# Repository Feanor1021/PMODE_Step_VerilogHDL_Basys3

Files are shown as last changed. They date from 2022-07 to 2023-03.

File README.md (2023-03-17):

# PMODE Step VerilogHDL Basys3

Basys3 Board

This project contains the Verilog HDL code for implementing a PMODE step on the Basys3 FPGA development board.

## Overview

The PMODE step is a useful circuit for controlling the direction of rotation of a stepper motor. The PMODE step circuit consists of four switches (SW0-SW3) and four output pins (LED0-LED3). When the switches are pressed in a particular sequence, the corresponding LED pins will light up in a particular sequence. This sequence of LED pin activations determines the direction and speed of the stepper motor.

PMODE Step Circuit

## Design

The PMODE step circuit is implemented using Verilog HDL. The design consists of a state machine that controls the behavior of the circuit based on the input from the four switches. The state machine has four states, each corresponding to a particular sequence of LED pin activations. The state machine transitions between these states based on the input from the switches.

The Verilog HDL code is written to be compatible with the Basys3 FPGA development board. The input signals are read from the switches and the output signals are written to the LED pins on the board.

## Usage

To use this Verilog HDL code on the Basys3 FPGA development board, follow these steps:

1. Clone or download this repository.
2. Open the project in a Verilog HDL synthesis tool such as Xilinx Vivado or Intel Quartus Prime.
3. Synthesize the design and generate the bitstream.
4. Program the bitstream onto the Basys3 FPGA development board.

Once the bitstream has been programmed onto the board, you can test the circuit by pressing the switches in the appropriate sequence and observing the LED pins.

## Credits

This project was developed by [Feanor1021](https://github.com/Feanor1021). The author would like to acknowledge the contributions of the Xilinx Vivado and Intel Quartus Prime tools to this project.

## License

This project is licensed under the MIT License. See the [LICENSE](LICENSE) file for details.

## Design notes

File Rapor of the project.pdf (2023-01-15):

Stepper Motor PMOD Reference Document

pg. 1

### KOCAELİ UNIVERSITY ENGINEERING FACULTY

# STEPPER MOTOR

# PMOD REFERENCE

# DOCUMENT

FURKAN YARDIMCI
2021-2022

### DEPARTMENT: Electronic and Communacition Engineering TEACHER: Associate Profesor ANIL ÇELEBİ

### KOCAELİ, 2021

TABLE OF CONTENTS

TABLE OF CONTENTS | 2
LIST OF FIGURES | 2
LIST OF TABLES | 2
PURPOSE OF THE PROJECT | 3
INTRO/OVERWİEV | 3
FEATURES | 3
CONNECTİONS/INTERFACING | 3
STEPPER MOTOR CONTROL | 4
VERILOG HDL | 5
•CODE | 5-9
- PMOD_STEP_DRIVER.V | 5-7
- CLOCK_DIV.V | 8
- PMOD_STEP_INTERFACE.V | 9
SCHEMATIC | 10
BORD LAYOUT | 10-12
MATERIAL LIST | 13
REFERENCES | 14

LIST OF FIGURES

STATE DIAGRAM OF THE CODE | 5
SCHEMATIC OF THE CIRCUIT | 10
TOP | 10
BOTTOM | 11
TOP/BOTTOM | 11
FOTAGE OF THE CIRCUIT(TOP) | 12
FOTAGE OF THE CIRCUIT(BOTTOM) | 12
MATERIAL LIST | 13

LIST OF TABLES

TABLE OF CONTENTS | 4
PURPOSE OF THE PROJECT | 4

PURPOSE:

The purpose of this document is to provide a document containing the necessary features about the design and use of stepper motor pmod, prepared by Kocaeli University Students FURKAN YARDIMCI and ASLINUR SERİN.

İNTRO/OVERWİEV:

The pmod stepper motor module provides the required number of headers to drive the 4-pin bipolar and 6-pin unipolar stepper motors with the Basys-3 board. Stepper motors are structures that contain magnets and coils that polarize this magnet to provide movement. When electric current passes through the coils in stepper motors, the motor creates torque due to the magnetic field created by this current. Each movement of this motor is called a step. The inputs of the Basys-3 card cannot provide this current required for the step motor to work. With the current/power amplifier circuit consisting of LM293D and mosfets on the pmod stepper module, it increases the low current it receives from the Basys-3 card to the levels that required for driving the stepper motor. In this way, the stepper motor is driven.

FEATURES:

- Stepper motor driver for 4 and 6-pin motors
- Can drive both motors simultaneously
- Multiple LEDs to indicate signal propagation
- Jumper for optional external power
- 2×6-pin pmod connector with GPIO interface

CONNECTİONS/INTERFACİNG:

The Pmod STEP communicates with the host board via the GPIO (General-purpose input/output) protocol. Microcontrollers usually include GPIOs. Depending on the application, a microcontroller's GPIOs may comprise its primary interface to external circuitry or they may be just one type of I/O used among several, such as analog signal I/O, counter/timer, and serial communication.

This Pmod offers headers for both 4-pin and 6-pin stepper motors. 4-pin stepper motors only work in the bipolar configuration, requiring that the two inputs on each electromagnetic coil are brought to the correct logic level voltages to induce current flow in the correct direction. The 6-pin stepper motor header on this Pmod can be oriented for either bipolar or unipolar configuration. The two extra pins on this header provide two positive power pins as a source of current for when an input on one end of a coil is driven to a logic low voltage level.

SM PMOD Reference Designator | Function
P2 | This pin 2x6, right-angle header provides VCC, GND and (8) digital 1/0 signals from the Basy3's microcontroller to the SM PMOD through any of the Pmod connector ports on the Basys-3.

P3 | 4-wire stepper motor interface connector.
P4 | 6-wire stepper motor interface connector.
P9 | This header provides access to pins 1-4 of the SM PMOD header J1 (labeled SIG1-SIG4 on the SM PMOD schematic).
P10 | This header provides access to pins 5-8 of the SM PMOD header J1 (labeled SIG5-SIG8 on the SM PMOD schematic).
P7 | GND
P8 | GND
P6 | External power screw terminal block. Provide power to the SM PMOD from an external source rather than from the Basys-3 board. NOTE: Pins 1 and 3 of P5 must be shorted (pins 2 and 3 of P5 open) to power the SM PMOD from an external source.
J1 | External power measurement point. Use P7 or P8 (GND) on SM PMOD as the return to measure the voltage of the external power applied to the board.
P5 | Power selection jumper. Jumper (short) pins 1 and 2 of P5 to supply power from the external power screw terminal block P6 or jumper (short) pins 2 and 3 of P5 to supply power from the Basys-3 board.
P1 | Digital I/O signal state indication LED power jumper. Install the jumper (short pins 1 and 2) on P1 to provide power to bias the digital 1/0 signal state indication LEDs. Remove the jumper to reduce power consumption of board for battery powered applications.

TABLE 1.

STEPPER MOTOR CONTROL:

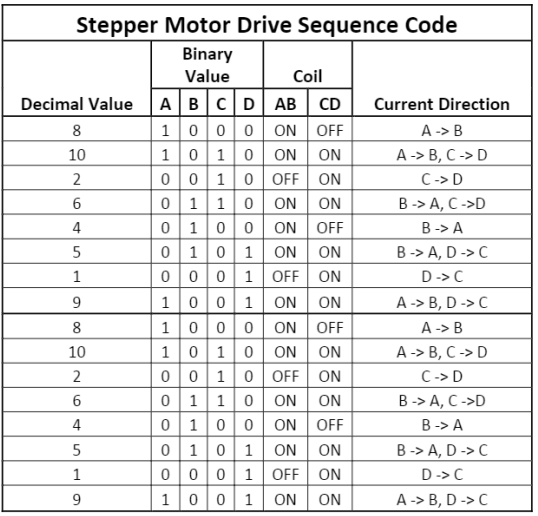
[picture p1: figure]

TABLE 2

VERİLOG HDL:

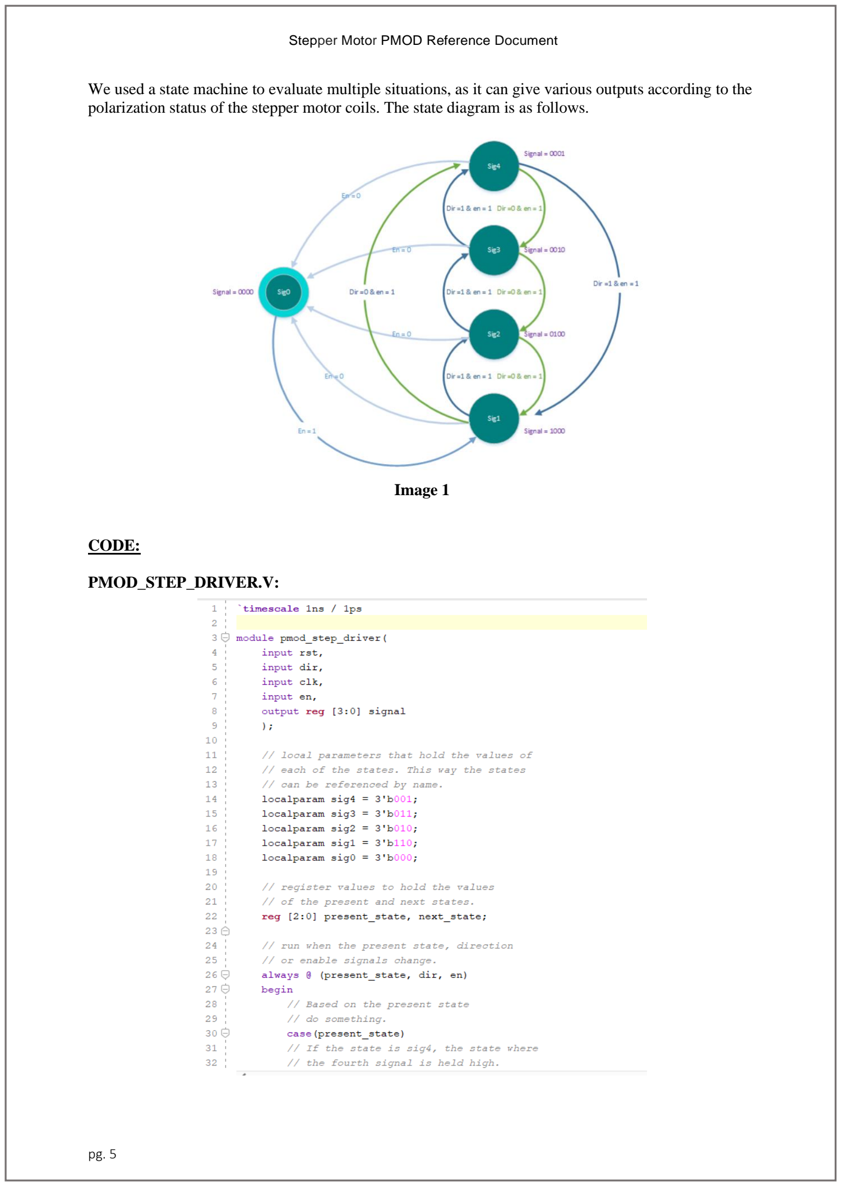
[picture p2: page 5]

We used a state machine to evaluate multiple situations, as it can give various outputs according to the polarization status of the stepper motor coils. The state diagram is as follows.

Image 1

CODE:

PMOD_STEP_DRIVER.V:

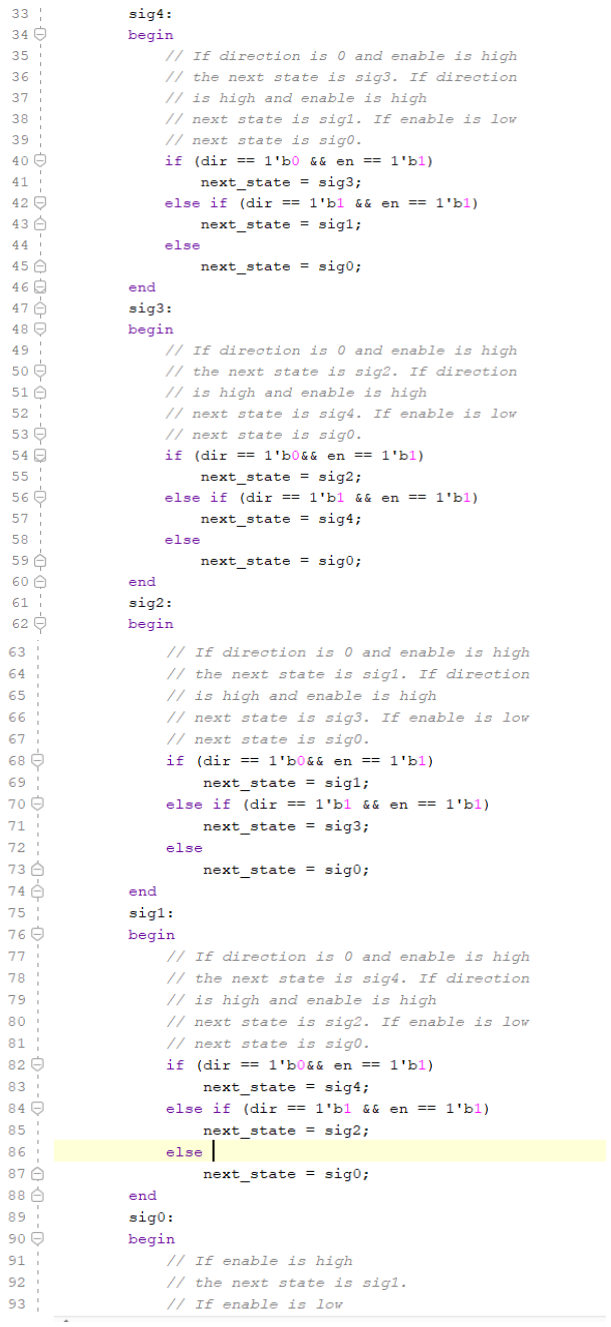
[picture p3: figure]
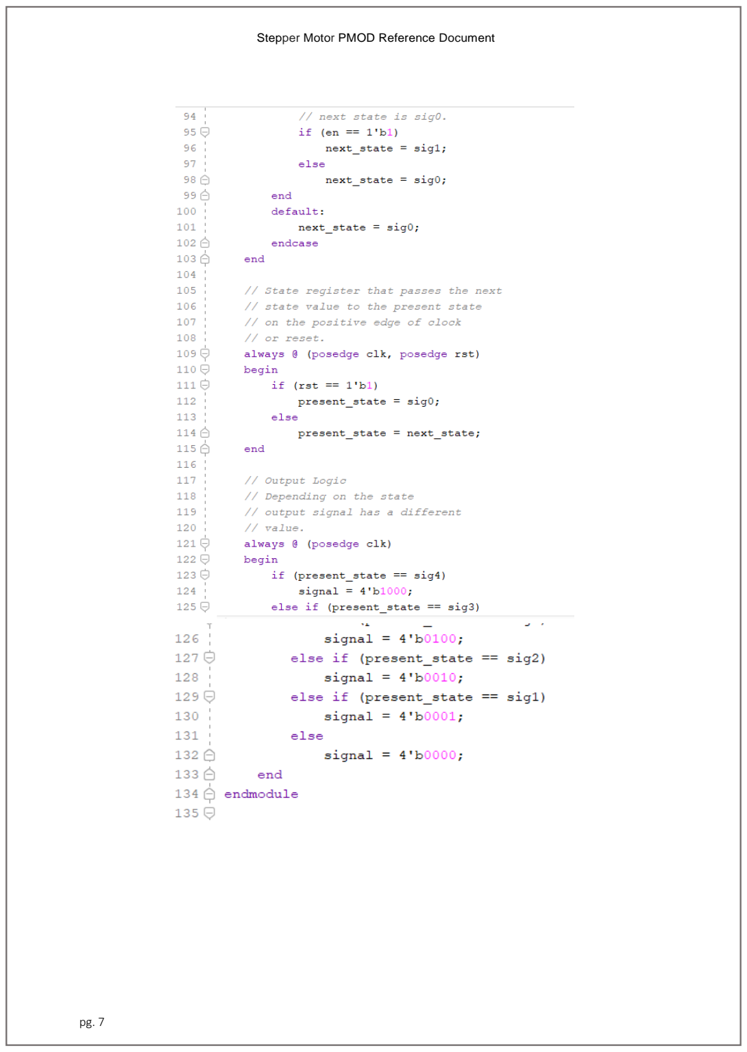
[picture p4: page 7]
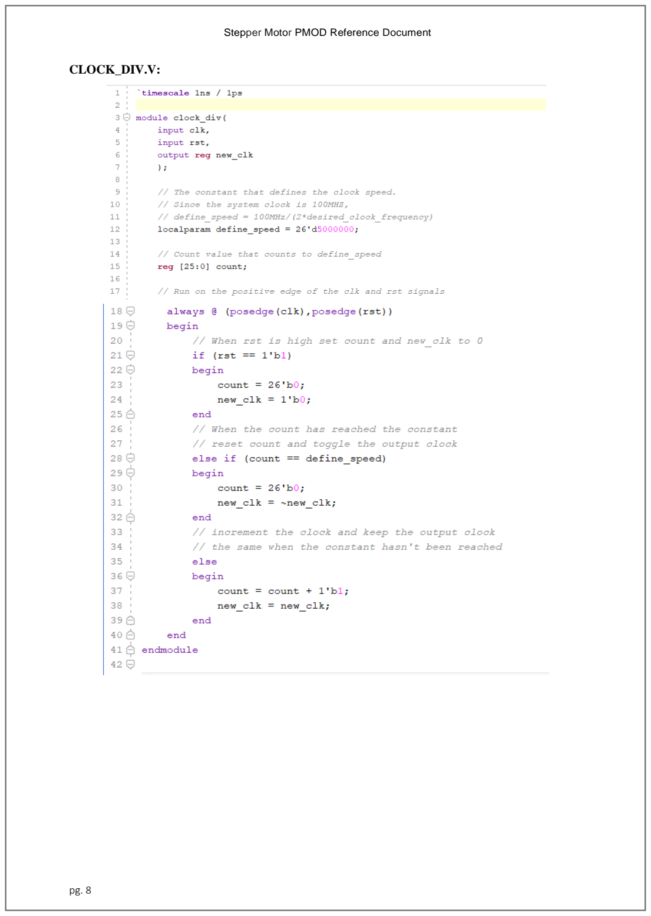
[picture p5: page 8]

CLOCK_DIV.V:

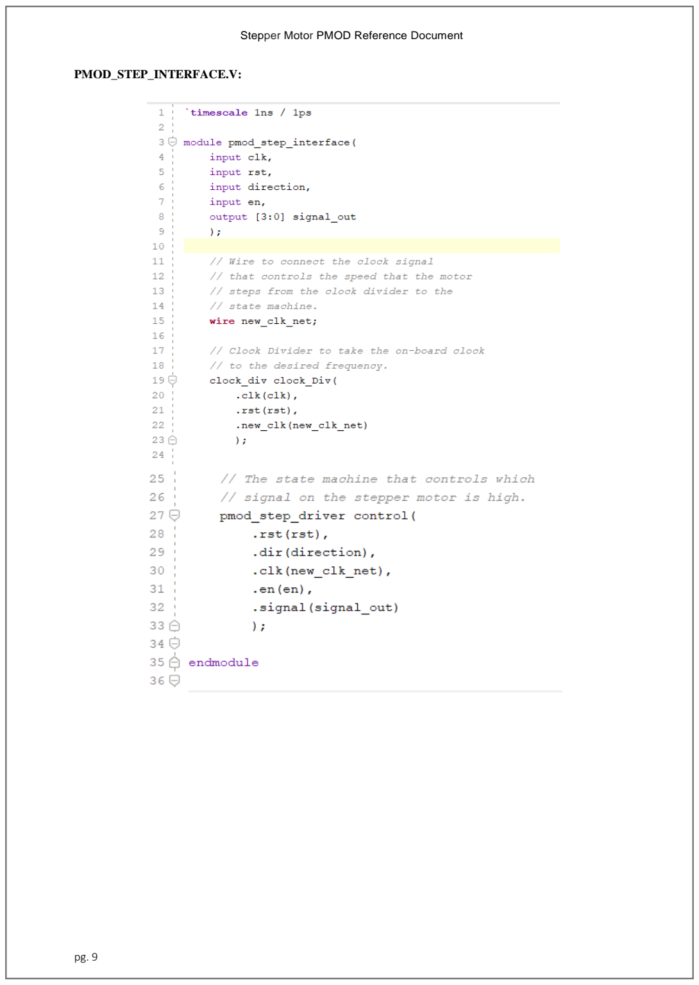
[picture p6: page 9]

PMOD_STEP_INTERFACE.V:

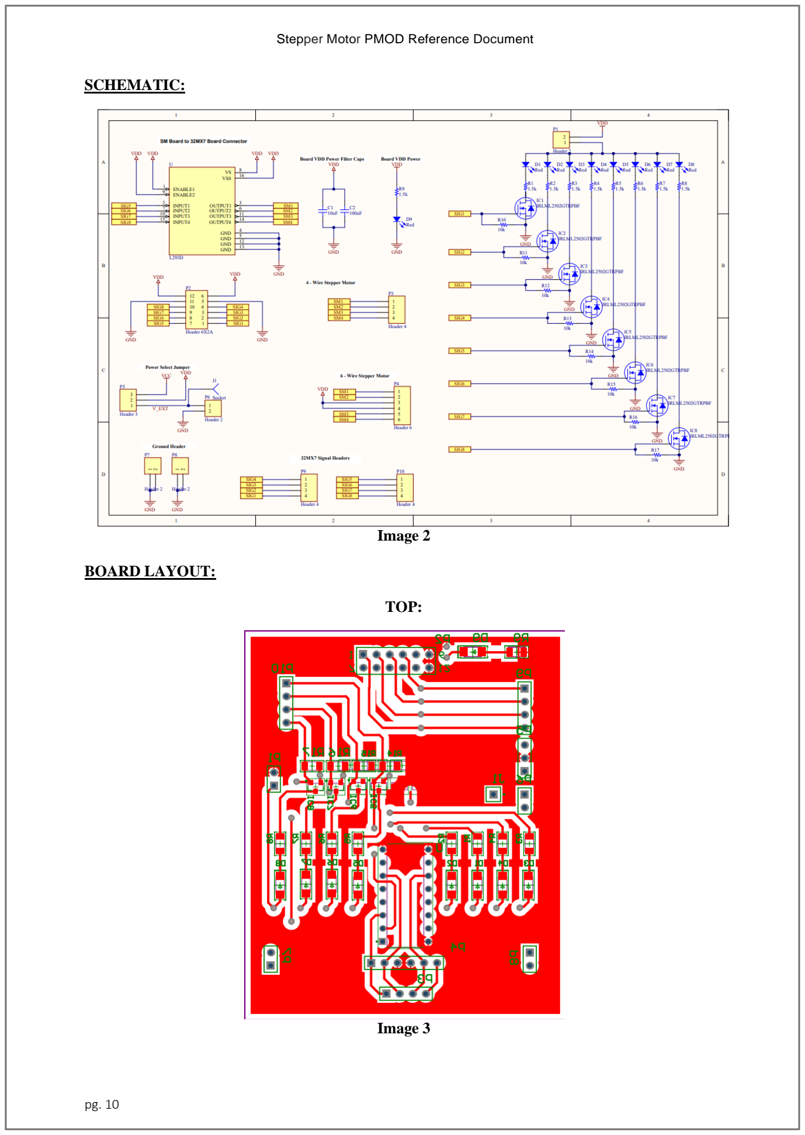
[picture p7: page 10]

SCHEMATIC:

Image 2

BOARD LAYOUT:

TOP:

Image 3

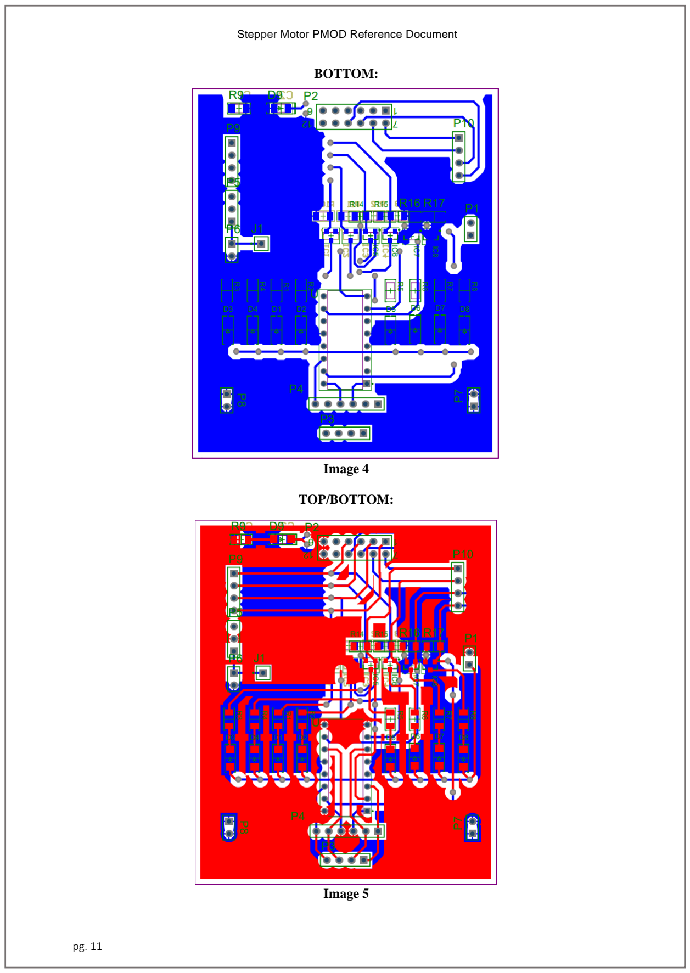
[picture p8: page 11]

BOTTOM:

Image 4

TOP/BOTTOM:

Image 5

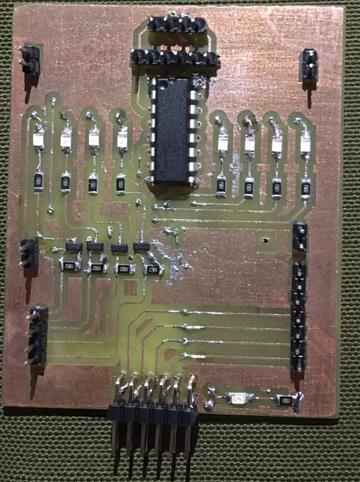
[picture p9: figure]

Image 6

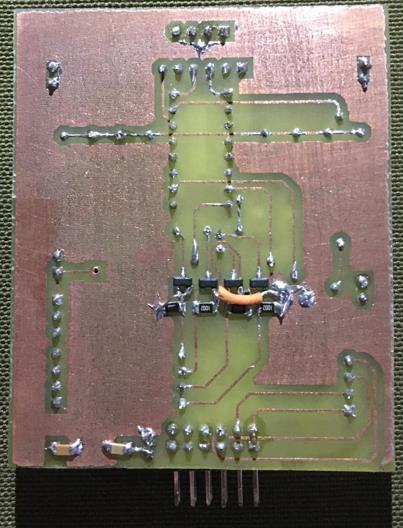
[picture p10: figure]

Image 7

MATERIALS LIST:

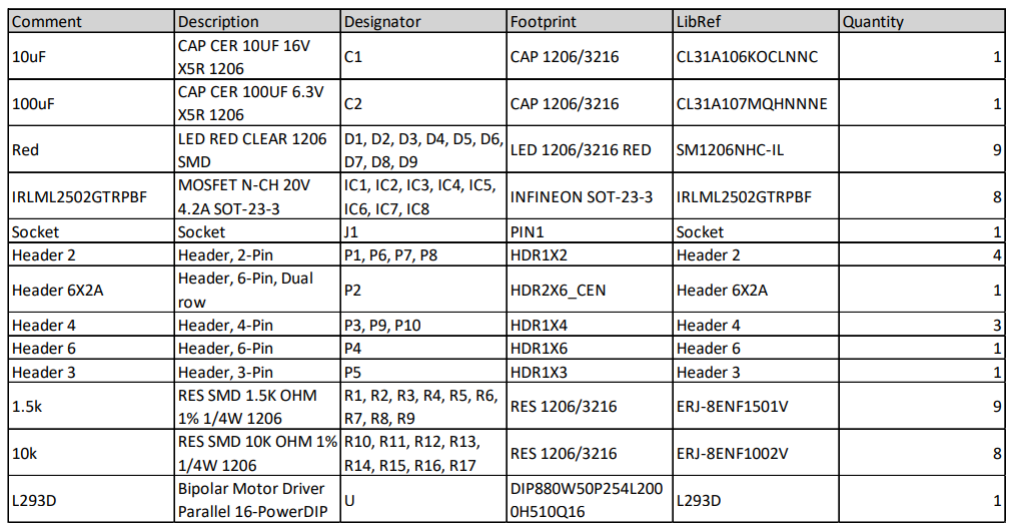
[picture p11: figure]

Image 8

REFERENCES:

- https://www.elektrovadi.com/urun/pmod-step-motor-surucu-pmod-stepper
- https://digilent.com/reference/pmod/pmodstep/reference-manual?redirect=1
- https://www.robocombo.com/blog/icerik/step-motor-nedir-ne-ise-yarar-nasil-calisir
- https://digilent.com/reference/learn/fundamentals/communication-protocols/gpio/start
- https://www.instructables.com/How-to-Control-a-Stepper-Motor-With-an-FPGA/
- https://www.youtube.com/watch?v=ePSCZ_DtF7c
- https://howtomechatronics.com/how-it-works/electrical-engineering/stepper-motor/

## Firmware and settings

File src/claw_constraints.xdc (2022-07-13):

## Clock signal
set_property PACKAGE_PIN W5 [get_ports clk]							
	set_property IOSTANDARD LVCMOS33 [get_ports clk]
	#create_clock -add -name sys_clk_pin -period 10.00 -waveform {0 5} [get_ports clk]
	
#Buttons
    set_property PACKAGE_PIN U18 [get_ports rst]                        
        set_property IOSTANDARD LVCMOS33 [get_ports rst]

# Switches
set_property PACKAGE_PIN V17 [get_ports {direction}]					
	set_property IOSTANDARD LVCMOS33 [get_ports {direction}]
set_property PACKAGE_PIN V16 [get_ports {en}]					
    set_property IOSTANDARD LVCMOS33 [get_ports {en}]
	
##Pmod Header JC
    ##Sch name = JC1
#    set_property PACKAGE_PIN K17 [get_ports {JC[0]}]                    
#        set_property IOSTANDARD LVCMOS33 [get_ports {JC[0]}]
    ##Sch name = JC2
    #set_property PACKAGE_PIN M18 [get_ports {JC[1]}]                    
        #set_property IOSTANDARD LVCMOS33 [get_ports {JC[1]}]
    ##Sch name = JC3
    #set_property PACKAGE_PIN N17 [get_ports {JC[2]}]                    
        #set_property IOSTANDARD LVCMOS33 [get_ports {JC[2]}]
    ##Sch name = JC4
    #set_property PACKAGE_PIN P18 [get_ports {JC[3]}]                    
        #set_property IOSTANDARD LVCMOS33 [get_ports {JC[3]}]
    #Sch name = JC7
    set_property PACKAGE_PIN L17 [get_ports {signal_out[0]}]                    
        set_property IOSTANDARD LVCMOS33 [get_ports {signal_out[0]}]
    #Sch name = JC8
    set_property PACKAGE_PIN M19 [get_ports {signal_out[1]}]                    
        set_property IOSTANDARD LVCMOS33 [get_ports {signal_out[1]}]
    #Sch name = JC9
    set_property PACKAGE_PIN P17 [get_ports {signal_out[2]}]                    
        set_property IOSTANDARD LVCMOS33 [get_ports {signal_out[2]}]
    #Sch name = JC10
    set_property PACKAGE_PIN R18 [get_ports {signal_out[3]}]                    
        set_property IOSTANDARD LVCMOS33 [get_ports {signal_out[3]}]
        
        
#         #leds
#           set_property PACKAGE_PIN U16 [get_ports {signal_out[0]}]                    
#               set_property IOSTANDARD LVCMOS33 [get_ports {signal_out[0]}]
#           #Sch name = JC8
#           set_property PACKAGE_PIN E19 [get_ports {signal_out[1]}]                    
#               set_property IOSTANDARD LVCMOS33 [get_ports {signal_out[1]}]
#           #Sch name = JC9
#           set_property PACKAGE_PIN U19 [get_ports {signal_out[2]}]                    
#               set_property IOSTANDARD LVCMOS33 [get_ports {signal_out[2]}]
#           #Sch name = JC10
#           set_property PACKAGE_PIN V19 [get_ports {signal_out[3]}]                    
#               set_property IOSTANDARD LVCMOS33 [get_ports {signal_out[3]}]
               
               
               set_property CFGBVS Vcco [current_design]
               set_property config_voltage 3.3 [current_design]
